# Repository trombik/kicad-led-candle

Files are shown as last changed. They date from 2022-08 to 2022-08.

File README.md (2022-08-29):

# LED candle

A simple LED candle using ATTiny AVR MCUs.

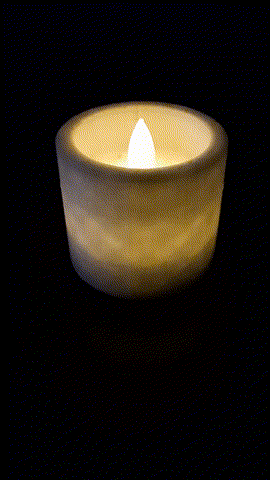
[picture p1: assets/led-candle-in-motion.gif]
LED candle in motion

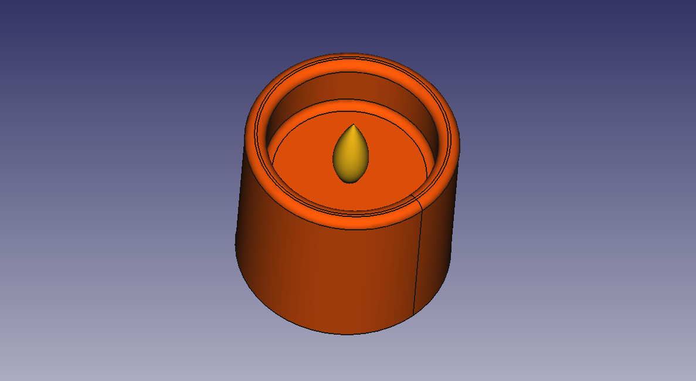
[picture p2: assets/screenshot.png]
3D model of LED candle

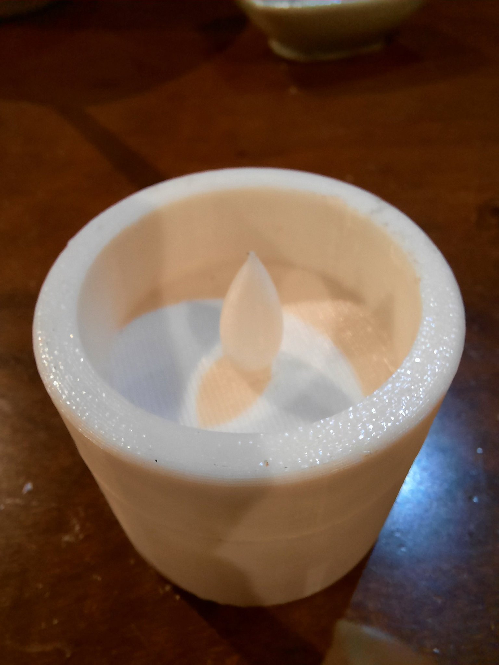
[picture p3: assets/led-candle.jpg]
LED candle

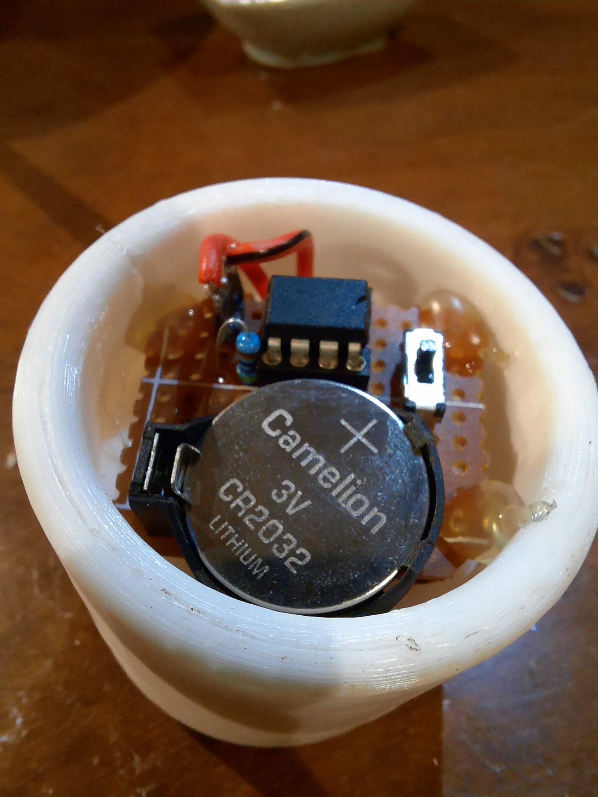
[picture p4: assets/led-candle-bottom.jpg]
bottom view of LED candle

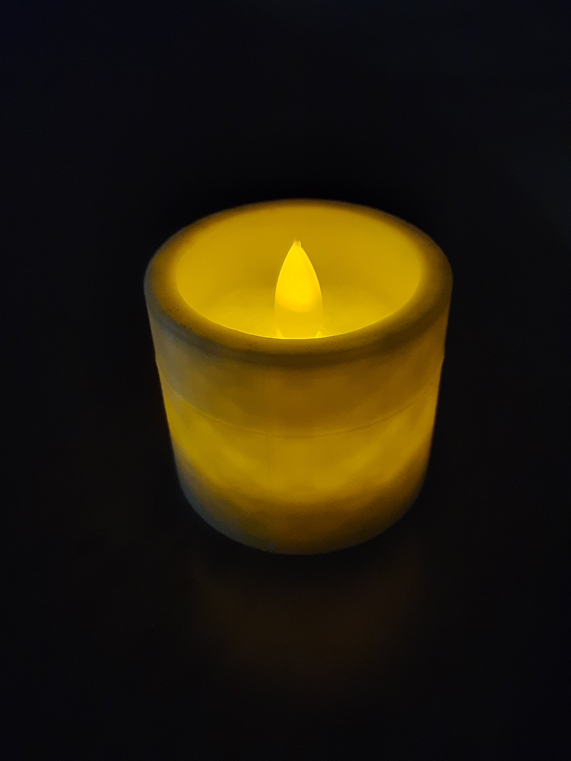
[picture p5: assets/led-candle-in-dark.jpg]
LED candle in the dark


## Building

```console
pio run
```

or building a specific target

```console
pio run -e attiny13a
```

## Build flags

### White noise

`-D USING_WHITE_NOISE` uses `rand()`, instead of "pink" noise, for changing
the duty. Requires more flash memory.

### Floating point math

`-D USING_PINK_NOISE_FLOAT` uses floating point math version of `pink_noise()`.
Requires more flash memory.

## Debugging

```console
pio debug -e attiny13a --interface=gdb -- -x init
```

# LICENSE

MIT. See [LICENSE](LICENSE).

[tiny_random.c](src/tiny_random.c) and [tiny_random.h](src/tiny_random.h) are
licensed under 3-clause BSD license.

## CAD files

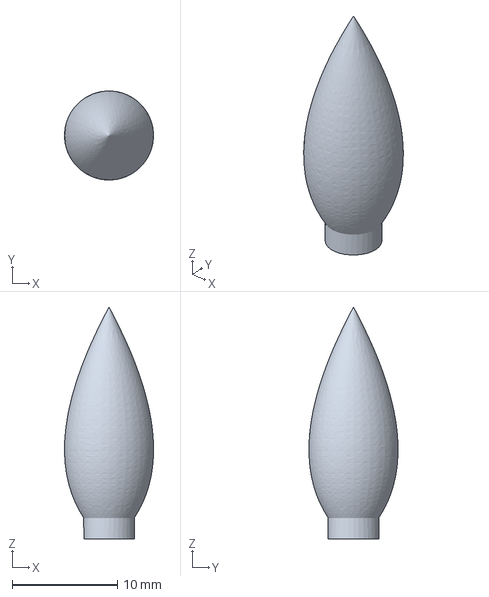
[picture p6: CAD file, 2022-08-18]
freecad/BB1_led-candle-fire.3mf
8.45 x 8.45 x 22.0 mm

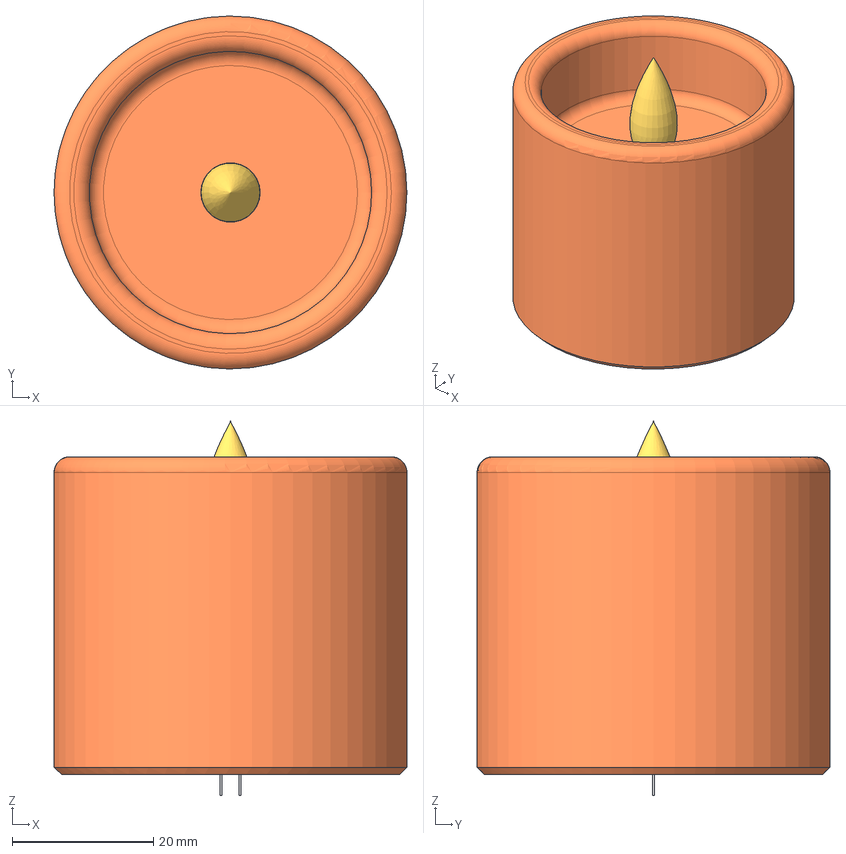
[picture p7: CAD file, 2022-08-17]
freecad/led-candle.FCStd
50.0 x 50.0 x 53.0 mm
Candle
fire
LED

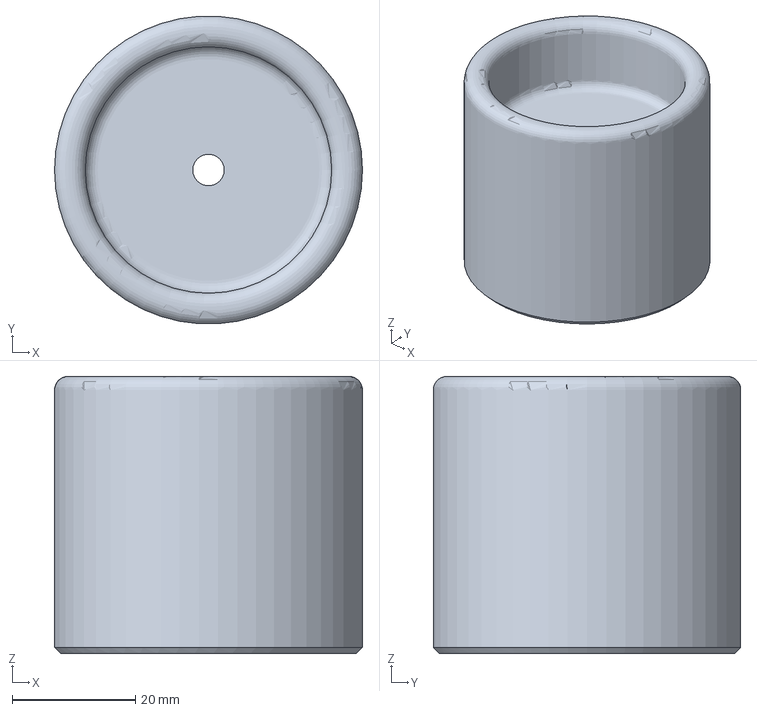
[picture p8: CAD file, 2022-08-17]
freecad/BB1_led-candle-Candle.3mf
50.0 x 49.9 x 45.0 mm

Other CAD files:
freecad/led-candle-fire.stl
freecad/led-candle-Candle.stl

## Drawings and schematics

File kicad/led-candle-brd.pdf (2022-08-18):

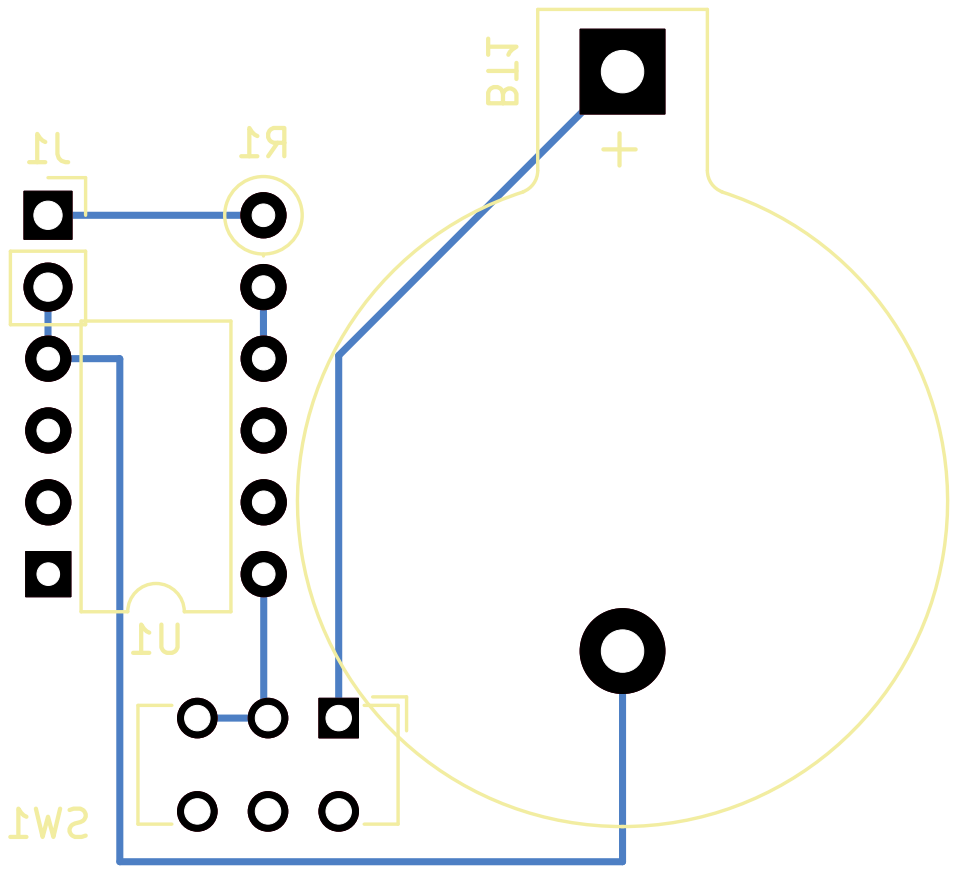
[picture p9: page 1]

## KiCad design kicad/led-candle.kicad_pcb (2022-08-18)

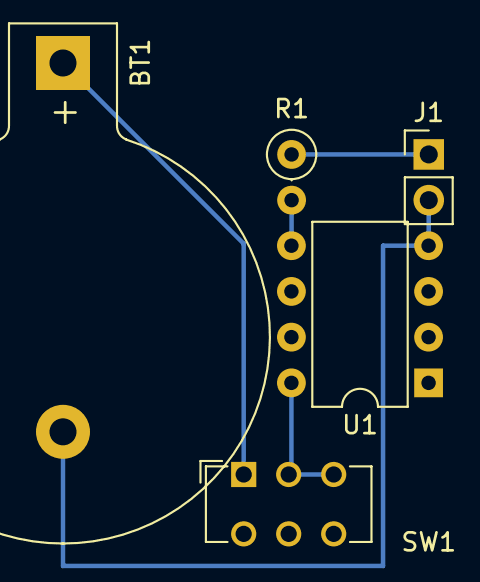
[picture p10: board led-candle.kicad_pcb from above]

Board: 2 copper layers, 5 parts (0 on the bottom side), 5 nets.

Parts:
BT1: Battery_Cell; BatteryHolder_Keystone_103_1x20mm
J1: Conn_01x02; PinHeader_1x02_P2.54mm_Vertical
R1: 220; R_Axial_DIN0207_L6.3mm_D2.5mm_P2.54mm_Vertical
SW1: SW_SPDT; SW_CuK_JS202011CQN_DPDT_Straight
U1: ATtiny13A-P; DIP-8_W7.62mm

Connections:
GND: BT1.2 (-), J1.2, U1.4 (GND)
LED: J1.1, R1.1
unnamed: BT1.1 (+), SW1.1 (A)
unnamed: R1.2, U1.5 (PB0)
VCC: SW1.2 (B), SW1.3 (C), U1.8 (VCC)

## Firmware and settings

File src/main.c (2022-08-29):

/*
 * Copyright (c) 2022 Tomoyuki Sakurai <y@trombik.org>
 *
 * Permission to use, copy, modify, and distribute this software for any
 * purpose with or without fee is hereby granted, provided that the above
 * copyright notice and this permission notice appear in all copies.
 *
 * THE SOFTWARE IS PROVIDED "AS IS" AND THE AUTHOR DISCLAIMS ALL WARRANTIES
 * WITH REGARD TO THIS SOFTWARE INCLUDING ALL IMPLIED WARRANTIES OF
 * MERCHANTABILITY AND FITNESS. IN NO EVENT SHALL THE AUTHOR BE LIABLE FOR
 * ANY SPECIAL, DIRECT, INDIRECT, OR CONSEQUENTIAL DAMAGES OR ANY DAMAGES
 * WHATSOEVER RESULTING FROM LOSS OF USE, DATA OR PROFITS, WHETHER IN AN
 * ACTION OF CONTRACT, NEGLIGENCE OR OTHER TORTIOUS ACTION, ARISING OUT OF
 * OR IN CONNECTION WITH THE USE OR PERFORMANCE OF THIS SOFTWARE.
 */

#include <Arduino.h>
#include <avr/io.h>
#include <util/delay.h>

#if defined(USING_PINK_NOISE_FLOAT)

/* rand() is defined in stdlib.h */
#include <stdlib.h>
#endif

/* due to size limit in flash memory, use small PRNG instead of rand() in
 * avr-libc.
 */
#include "tiny_random.h"

/* the initial seed for tiny_random() */
#define PRNG_SEED 0xDEAD

/* time to delay */
#define DELAY_MS (70)

/* generates pink noise, aka 1/f noise. returns 0..1000. uses floating point
 * math. too big for attiny13a.
 *
 * use it when flash memory size permits.
 */
#if defined(USING_PINK_NOISE_FLOAT)
static int
pink_noise(void)
{
	static int value = 0.1;
	if (value < 0.5) {
		value += value * value * 2;
	} else {
		value -= (1.0 - value) * (1.0 - value) * 2;
	}

	/* as the value tends to stay both ends of the range, use random */
	if (value < 0.1 || value > 0.9) {
		value = rand() / RAND_MAX;
	}
	/* multiply by 1000 for compatibility in main() */
	return value * 1000;
}
#elif defined(USING_WHITE_NOISE)
static int
white_noise(void)
{
	return tiny_random() / (0xffff / 1000) + 1;
}
#else

/* integer version of pink_noise(). does not use floating point math. */
static int
pink_noise(void)
{
	static int value = 100;
	if (value < 500) {
		value += (value * value / 1000) * 2;
	} else {
		value -= ((1000 - value) * (1000 - value) / 1000) * 2;
	}

	if (value < 100 || value > 900) {
		value = tiny_random() / ((0xffff / 1000) + 1);
	}
	return value;
}
#endif

int duty;

int
main(void)
{

	/* configure PB0 and PB1 as output */
	pinMode(0, OUTPUT);
	pinMode(1, OUTPUT);

	/* set initial state to off */
	digitalWrite(0, LOW);
	digitalWrite(1, LOW);

	/* initialize PRNG */
	tiny_random_init(PRNG_SEED);

	for (;;) {
#if defined(USING_WHITE_NOISE)
		duty = white_noise();
#else
		duty = pink_noise();
#endif
		analogWrite(0, duty);

		/* another (optional) LED for reversed phase */
		analogWrite(1, 0xff - duty);
		_delay_ms(DELAY_MS);
	}
}

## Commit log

2022-08-17 feat: add the 3D models
    [BB1_led-candle-Candle.3mf, led-candle-Candle.stl, led-candle-fire.stl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]
2022-08-17 doc: add schematic
    [led-candle.kicad_pcb, led-candle.kicad_sch]
2022-08-18 feat: add PCB layout, remove optional LED from schematic
    [led-candle.kicad_pcb, led-candle.kicad_sch]
2022-08-18 feat: add project file for "fire"
    [BB1_led-candle-fire.3mf]
2022-08-18 bugfix: fix a track in PCB
    [led-candle.kicad_pcb]
2022-08-18 doc: add flipped PCB board in PDF
2022-08-29 bugfix: format, and use pinMode() instead of resister access
    [main.c]
